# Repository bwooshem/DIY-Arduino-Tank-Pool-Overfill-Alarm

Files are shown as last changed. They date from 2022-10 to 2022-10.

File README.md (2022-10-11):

# DIY-Arduino-Tank-Pool-Overfill-Alarm
CC-By-NC-SA [Brian Woo-Shem](https://www.brianwooshem.com): Design & programming for calibration tool, documentation, testing and validation.

Alarm when a pool, fish tank, or other reservoir filled via hose is about to overflow. Uses Arduino and Ultrasonic sensor.

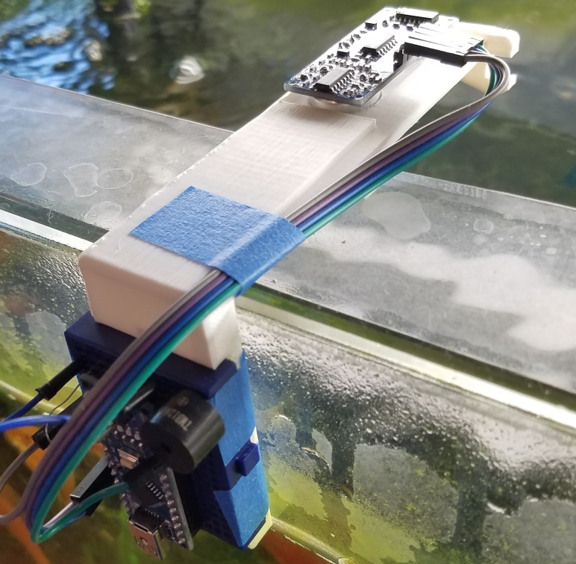
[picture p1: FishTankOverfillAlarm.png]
Overfill alarm in use


The original device was built after a giant fish tank I fill via hose overflowed because nobody was paying attention. After cleaning up the mess, I decided to build a sensor to prevent such accidents. Ultrasonic is a good choice because it bounces sound waves off of another surface and detects how long it takes to reflect back. The water has sufficiently different speed of sound, so it acts as a practically solid surface. Thus, there is no need to physically touch or put anything in the water to detect it.

The 3D printed mount fits my particular fish tank; the .STL and .SLDPRT files are included so others can modify it to fit their systems. Feel free to fork or create a pull request with CAD for mountings to other things. 

With a little creativity, mounts or connectors to swimming pools, ponds, and other things can be made; the only requirement is the Ultrasonic must be perpendicular to and directly above the water.

## Materials
- Arduino: Nano, Uno, or Mega will all work
- Ultrasonic Sensor HC-SRO4
- Piezo Buzzer
- 4x In-Out jumper wires
- 3x out-out jumper wires
- Small breadboard
- Resistor: 100Ω-10kΩ
- 3D Printed mounting (optional)

## Instructions

1. Wire the Ultrasonic Sensor -> Arduino:
    1. VCC  -> 5VDC
    1. TRIG -> Pin 9
    1. ECHO -> Pin 8
    1. GND  -> GND

2. Connect the resistor to pin D3 (you can use any PWM pin as long as you change the variable in _FishTankOverfillSensorUltrasonicBuzzer.ino_).
3. Connect the piezo to the other side of the resistor
4. Connect the other leg of the piezo to GND
5. Load _FishTankOverfillSensorUltrasonicBuzzer.ino_ onto the Arduino. Use Arduino IDE, see this [guide](https://www.arduino.cc/en/Guide/Environment) if you are unfamiliar with it.
6. (Optional) mount onto 3D printed clip

Also see the [circuit on TinkerCAD](https://www.tinkercad.com/things/g29VphFcNcn)

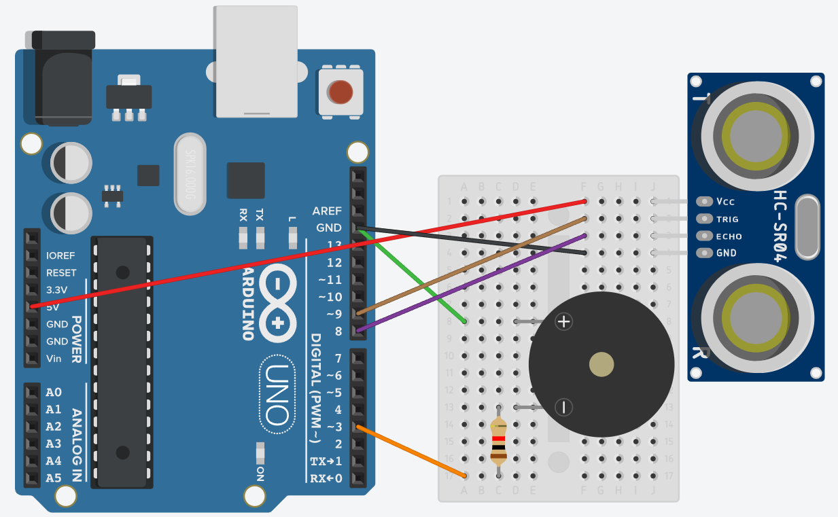
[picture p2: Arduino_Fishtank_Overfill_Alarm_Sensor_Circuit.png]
Circuit Diagram


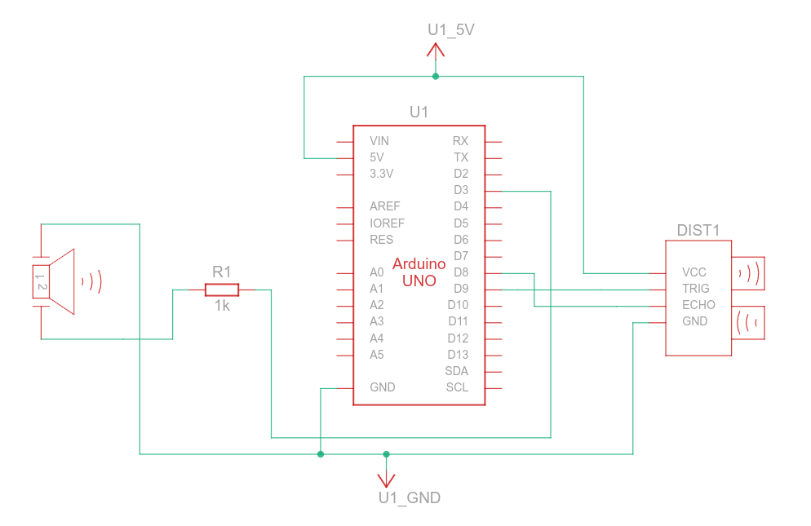
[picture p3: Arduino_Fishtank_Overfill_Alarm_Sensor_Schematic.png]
Circuit Schematic


## License

All text, graphics, and non-code content is licensed [CC BY-NC-SA](https://creativecommons.org/licenses/by-nc-sa/4.0/)    
All code is licensed under the [GNU General Public License v3](https://www.gnu.org/licenses/gpl-3.0.en.html)

RTClib and Adafruit_SCD30 are Copyright (c) Adafruit Industries and used under the open source MIT license.   
Arduino IDE and related components are open source and licensed under the GNU GPL v2 and/or CC BY-SA Arduino.

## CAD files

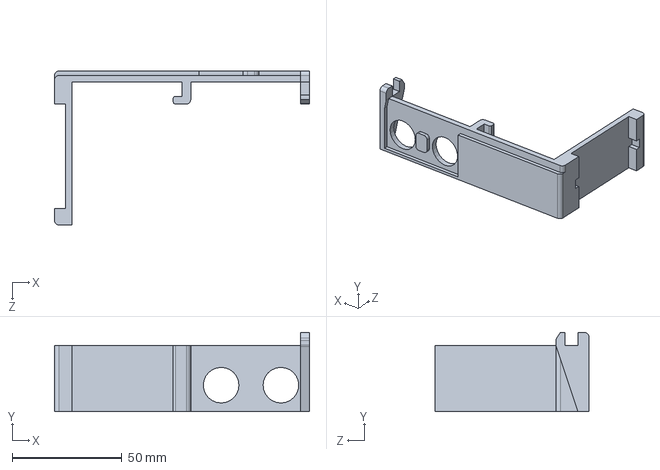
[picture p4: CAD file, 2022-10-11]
FishTankOverfillSensorMount_4.SLDPRT
116.0 x 36.0 x 70.0 mm

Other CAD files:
FishTankOverfillSensorMount_4.STL

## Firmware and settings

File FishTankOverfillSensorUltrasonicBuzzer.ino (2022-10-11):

/*
 * Fish Tank Overfill Sensor
 * Ultrasonic & Piezo Buzzer
 * Intended for Arduino Nano, should also work for Uno & Mega.
 * Copyright (C) Brian Woo-Shem
 * 2021-09-11
 * v1.1
 *
 * https://github.com/bwooshem/DIY-Arduino-Tank-Pool-Overfill-Alarm
 *
 * Wiring: Ultrasonic Sensor -> Arduino:
 * - VCC  -> 5VDC
 * - TRIG -> Pin 9
 * - ECHO -> Pin 8
 * - GND  -> GND
 *
 * Wiring: Piezo -> Arduino:
 * - Pin 3 -> 100 Ohm Resistor -> Piezo -> Ground
 *
 * 
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
 *  This program is distributed in the hope that it will be useful, but WITHOUT ANY WARRANTY; without 
 *  even the implied warranty of MERCHANTABILITY or FITNESS FOR A PARTICULAR PURPOSE. See the 
 *  GNU General Public License at https://www.gnu.org/licenses/gpl-3.0.en.html for more details.
 */

int trigPin = 9;    // TRIG pin
int echoPin = 8;    // ECHO pin
const int piezo = 3;
const int warning = 5; //cm
const int alarm = 3; //cm


float duration, distance, d;

void setup() {
  // begin serial port for debugging. Line can probably be removed.
  Serial.begin (9600);

  // configure the trigger pin to output mode
  pinMode(trigPin, OUTPUT);
  // configure the echo pin to input mode
  pinMode(echoPin, INPUT);

  pinMode(piezo, OUTPUT);
}

void loop() {

  // Get distance in cm
  d = ultradist(trigPin,echoPin);
  // If distance less than 10cm
  if (d < warning){
    // If distance less than alarm cm, play alarm
    if (d < alarm){
      // Play high alert sound in Hz (A4 and E5) in 1s on, 1s off pattern
      tone(piezo, 440);
      delay(1000);
      tone(piezo,659.3);
      delay(1000);
      noTone(piezo);
    }
    else{
      // Warning
      //Play gentle alert sound in Hz (G3) in 0.3s on, 1.7s off pattern
      tone(piezo, 196);
      delay(300);
      noTone(piezo);
      delay(1700);
    }
    
  }

  delay(5000); //Wait 5s before next alarm sound; remove if you want the alarm to be harder to ignore.
}


// Function for the Ultrasonic sensor to read different distances. Returns distance in cm
float ultradist(int trigPin, int echoPin){
      digitalWrite(trigPin, HIGH);
      delayMicroseconds(10);
      digitalWrite(trigPin, LOW);
    
      // measure duration of pulse from ECHO pin
      duration = pulseIn(echoPin, HIGH);
    
      // calculate the distance
      d = 0.017 * duration;
      // Print current ultrasonic reading to the monitor for debugging purposes; comment out if not needed
      //Serial.println(d);
      return d; //current distance
}

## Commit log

2022-10-11 Circuit diagram
2022-10-11 Circuit Schematic
2022-10-11 Create documentation w/circuit diagrams

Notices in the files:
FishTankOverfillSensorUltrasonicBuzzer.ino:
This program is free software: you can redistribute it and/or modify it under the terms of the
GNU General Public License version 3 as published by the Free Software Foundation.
